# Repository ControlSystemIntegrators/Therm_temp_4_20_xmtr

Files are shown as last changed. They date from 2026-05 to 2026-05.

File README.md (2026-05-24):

# Analog 4–20 mA Thermistor Temperature Transmitter

A fully **analog** (no microcontroller) 2-wire 4–20 mA temperature transmitter
built from **standard, multi-sourced parts** — and a worked tutorial in the
instrumentation theory behind it.

It does two jobs:

1. **A teaching reference.** If you've ever wanted to understand how a 4–20 mA
   transmitter actually works — loop power, sensor excitation, linearization,
   zero/span calibration — this is a complete, honest, end-to-end example with
   the math shown and a calculator you can run.
2. **A real instrument.** It was designed for **chocolate temperature control**
   (the 20–40 °C tempering/working range), as a more accurate and more robust
   replacement for thermocouples. But it is parameterized: point the included
   calculator at *your* thermistor and *your* temperature band and it tells you
   which resistors to fit.

> **Why analog?** You can absolutely bolt a microcontroller and a 12-bit ADC on
> top of this for fine digital adjustment — see [Optional digital
> upgrade](#optional-digital-upgrade). In practice, for "hold a setpoint in a
> known band" process control, that layer is rarely worth the complexity. This
> project deliberately stays in the analog domain so the whole signal path is
> visible and every part is replaceable.

> **Not a safety device.** This is a process measurement instrument, not a
> safety-rated (SIL) one. Don't use it as a protective function.

---

## Specifications (default build)

| Parameter | Value |
|---|---|
| Output | 4–20 mA, 2-wire loop-powered |
| Loop supply | 7–30 V (24 V typical) |
| Default range | **20–40 °C → 4–20 mA** (chocolate) |
| Sensor | NTC thermistor, 10 kΩ @ 25 °C, β ≈ 3892 K (e.g. Omega 44006) |
| In-band accuracy | **±0.1 °C over the 20 °C band** (realistic system figure; the electronics + linearization contribute only ~±0.06 °C — sensor interchangeability, self-heating and lead effects dominate) |
| Calibration | zero + span trimpots, non-interactive |
| Quiescent current | ~2.6 mA (fits under the 4 mA floor) |
| Components | jellybean / multi-sourced; op-amps in SOT-23-5 |

Outside the chosen band the output saturates near 4 mA (cold) or 20 mA (hot) —
intentional. Accuracy is only specified inside the band.

---

## How a 4–20 mA transmitter works (the theory)

**The current loop.** A 2-wire transmitter sits in series with a DC supply and
a receiver. The transmitter's job is to *draw a controlled current* from the
loop — 4 mA represents the bottom of the range, 20 mA the top — regardless of
loop voltage or wiring resistance (within limits). Because the *current* is the
signal, voltage drops in long cable runs don't corrupt the reading, and a broken
wire reads 0 mA (a detectable fault, distinct from a valid 4 mA "low"). That
noise immunity and fault detection is why 4–20 mA has survived for decades in
industry.

**Loop-powered ("2-wire").** The same two wires that carry the signal also power
the transmitter. The catch: the *entire* circuit must run on **less than 4 mA**,
because that floor is the lowest the loop ever provides. Every microamp the
electronics draw is part of the loop current, so the design budgets quiescent
current carefully and lets an output ("dump") transistor make up the difference
to hit the commanded 4–20 mA.

**Why a thermistor?** An NTC thermistor is cheap, has a large signal (thousands
of ohms change over our band), is available with tight interchangeability
(±0.1–0.2 °C for the Omega 44000 series), and needs no cold-junction
compensation like a thermocouple. Its one drawback is that it is **very
nonlinear** — which is the interesting part of this design.

---

## The nonlinearity problem (and the one-resistor fix)

An NTC's resistance is approximately

```
R(T) = R25 · exp( β · (1/T − 1/298.15) )      [T in kelvin]
```

For our 10 kΩ part that's ~57 kΩ at −10 °C falling to ~3.6 kΩ at +50 °C — about
15:1, and badly curved. Fed straight into a linear amplifier you'd get large
errors away from one calibration point.

**The fix is a single resistor in parallel with the thermistor.** The parallel
combination `Rt ∥ Rlin` has an S-shaped curve with an inflection point; placing
that inflection at the *center* of your band makes the network resistance very
nearly linear in temperature there. The value for maximum linearity at center
temperature `Tc` (kelvin) is:

```
Rlin = Rt(Tc) · (β − 2·Tc) / (β + 2·Tc)
```

For the chocolate build (center 30 °C) the closed-form (unloaded) value is
~5.9 kΩ; the build uses **6.04 kΩ**, re-optimized for the gain-stage loading
(see [below](#dont-let-the-gain-stage-load-the-sensor)). Either way the residual
nonlinearity across 20–40 °C is only ~**±0.06 °C** — comfortably inside the
±0.1 °C system spec, so the linearization is never the limiting term.

### Why one resistor and not two

A second resistor *can* add a curvature-shaping term (by exciting through a
divider instead of a constant current), so we checked whether it's worth it.
For an NTC it essentially isn't — the optimizer drives the second resistor back
toward "constant current," and the conformity barely moves:

| Band → 4–20 mA | 1 resistor | 2 resistors |
|---|---|---|
| 20–40 °C | ±0.061 °C | ±0.057 °C |
| 15–45 °C | ±0.207 °C | ±0.188 °C |
| −10–50 °C | ±1.585 °C | ±1.545 °C |

~5% improvement for an extra precision part and an extra calibration
interaction. We dropped it. **The real lever is band width, not resistor count**
(see the table — the wider the band, the worse the conformity). Pick the
narrowest band that covers where your process actually operates.

### Don't let the gain stage load the sensor

There's a subtle trap the ideal math hides. The single-op-amp difference amp
(next stage) presents its input network — `R9 + R12` from the sensor node to
ground — as a *load* on node X. The sensor's source impedance there is the
linearized network (a few kΩ), so a low input impedance bleeds a
temperature-dependent current out of the node and **bows V(X)**, adding
nonlinearity the zero/span trims cannot remove.

We only caught this with the **device-level SPICE model** (the ideal netlist and
the first cut of `design.py` both assumed an infinite-impedance gain input). With
the original 10 k / 24.9 k divider (`R9+R12 ≈ 35 kΩ`) loading a ~4 kΩ source, the
in-band conformity blew out to **±0.18 °C** — past the spec. Two fixes, both
verified:

1. **Raise the gain-stage input impedance** so it stops loading the node — this
   build uses `R9=R10=100 kΩ`, `R11=R12=249 kΩ` (`R9+R12 ≈ 349 kΩ`, ~1 % loading).
2. **Re-optimize R1** for whatever loading remains — `design.py` now models the
   load (`--rload`) and searches for the best linearization resistor rather than
   trusting the unloaded closed form (hence 6.04 kΩ, not 5.9 kΩ).

With both, conformity is back to **±0.058 °C**, confirmed in the device-level
sim. Lesson: a difference amp driven from a non-trivial source impedance must
have an input impedance well above it, or you pay for it in linearity.

You can reproduce all of this — and design for your own sensor/range — with
[`tools/design.py`](tools/design.py).

---

## Circuit overview

Two views: the **signal chain** (what computes the current) and the
**power/output loop** (how a 2-wire device powers itself and sets loop current).

### Signal chain

```
 Vref(2.5V) ──[ NTC ∥ Rlin ]──● X ─────────────►┌────────────┐
                              │                 │   A2       │
              A1 sinks Iexc ──┘                 │ gain/zero  │─ Vcmd ─►┌──────────┐
              (0.25 mA, constant)               │  (2 pots)  │         │ A3 servo │─► loop
                                                └────────────┘         │  + Q2    │   current
   V(X) = Vref − Iexc·(NTC ∥ Rlin)                                     └──────────┘
        (rises with temperature)        Vcmd = SPAN·(V(X) − ZERO)   Iloop = Vcmd / Rsense
```

A constant current is pulled through the linearized network, so the node voltage
`V(X)` is a clean, near-linear function of temperature. The gain/zero amplifier
scales and offsets it; the output stage turns that command voltage into loop
current.

### Power / output loop

```
 LOOP+ ──▷|──┬───────────────────────────────┬──────────► IN (raw 7..30 V)
   (24 V) D1 │                               │
           TVS         pre-reg: Q1 + TL431 ───┤────────► VL (+5 V) ─► Vref, A1, A2, A3
            │          (series NPN follower)  │
            │                                 └────────► Q2 collector (dump)
            │                                                  │ emitter
 LOOP- ─────┴────────────────[ Rsense 50Ω ]──────  AGND ───────┘
                                    ▲
                A3 drives Q2 so that  Iloop · Rsense = Vcmd
```

Everything returns to `AGND` and flows out through `Rsense`, so the
sense resistor sees the **total** loop current — the electronics' own ~2.6 mA
quiescent draw plus whatever the dump transistor `Q2` adds. A3 servos `Q2` until
that total equals `Vcmd / Rsense`. Because quiescent draw (~2.6 mA) is below the
4 mA floor, `Q2` always has something to add.

### Stage-by-stage

| Stage | Parts | Function | Key relation |
|---|---|---|---|
| Protection | D1 (Schottky), TVS | reverse-polarity + surge | — |
| Pre-regulator | Q1 (NPN follower), TL431, divider, + Q4/Q5 bias source | makes the +5 V rail `VL` from the loop; **series** pass, not shunt, so it draws only what the electronics need. Q4/Q5 form a 2-transistor constant-current source (a jellybean replacement for a current-regulating diode) that biases the TL431 flat across the 7–30 V loop | `VL = 2.5·(1+Rfa/Rfb)` |
| Reference | LM4040-2.5 | 2.500 V for excitation + zero | — |
| Excitation | A1, Q3, Rexc | constant `Iexc = Vref/Rexc = 0.25 mA` pulled through `NTC∥Rlin` | `V(X)=Vref − Iexc·Rnet` |
| Linearization | Rlin (6.04 kΩ) | straighten the curve in-band | `Rlin = Rt(Tc)·(β−2Tc)/(β+2Tc)`, re-optimized for load |
| Gain/Zero | A2 + **span pot** + **zero pot** | scale & offset to the command voltage | `Vcmd = SPAN·(V(X) − ZERO)` |
| Output | A3, Q2, Rsense | servo loop current to the command | `Iloop = Vcmd / Rsense` |

> **The three knobs are orthogonal**, which makes calibration sane:
> **Rlin** depends only on the band *center*, **span** on the band *width*, and
> **zero** on the band *position*. Move the band up/down → re-zero only. Widen
> it → re-span only. Re-center it → change Rlin.

---

## Selecting components for your own range

Run the calculator with your sensor and the two temperatures you want at 4 mA
and 20 mA:

```
python3 tools/design.py --r25 10000 --beta 3892 --tlow 20 --thigh 40
```

It prints the linearization resistor, the excitation resistor, the span (gain)
and zero (offset) targets, the conformity error you'll get, the self-heating
estimate, and a transfer table. Defaults are the chocolate build. Output for the
default:

```
--- Linearization ---
Rlin (E96)      : 6.040 kohm   <- re-optimized for gain-stage loading
Conformity      : +/- 0.059 C
--- Excitation ---
Rexc (E96)      : 10.000 kohm  -> Iexc = 0.2500 mA
--- Amplifier / output stage ---
SPAN  (gain)    : 2.5706 V/V   <- set by span pot
ZERO  (Vzero)   : 1.3872 V     <- set by zero pot
```

**Manual recipe** (what the script does):

1. **Center → Rlin.** `Tc = (Tlow+Thigh)/2`; `Rlin = Rt(Tc)·(β−2Tc)/(β+2Tc)`,
   rounded to the nearest E96 value.
2. **Excitation.** Pick `Iexc` (~0.25 mA is a good balance of signal size vs.
   self-heating); set `Rexc = Vref / Iexc`.
3. **Edge voltages.** `V(X) = Vref − Iexc·(Rt ∥ Rlin)` at `Tlow` and `Thigh`.
4. **Span (gain).** `SPAN = (20mA−4mA)·Rsense / (V(X)@Thigh − V(X)@Tlow)`.
5. **Zero (offset).** Choose `ZERO` so the output is 4 mA at `Tlow`.

Then check the printed conformity. If it exceeds your target, your band is too
wide — narrow it (see the table above).

---

## Calibration

You need a way to present two known temperatures (a stirred ice/water-and-warm
bath, a dry-block calibrator, or — easiest for bench bring-up — **two precision
resistors** substituted for the probe equal to `Rt(Tlow)` and `Rt(Thigh)`, which
the calculator prints).

1. Apply the **low** point (`Tlow`, e.g. 20 °C → `Rt = 12.49 kΩ`). Adjust the
   **ZERO** pot for **4.00 mA**.
2. Apply the **high** point (`Thigh`, e.g. 40 °C → `Rt = 5.35 kΩ`). Adjust the
   **SPAN** pot for **20.00 mA**.
3. Repeat once. Zero and span interact only slightly (the gain term scales the
   zero point a little), so a second pass nails both to within a microamp.

Use a loop calibrator or a 250 Ω precision resistor + DMM (1.000–5.000 V = 4–20
mA) to read the current.

---

## Bill of materials (multi-sourced)

Every active part below is available from multiple manufacturers, or in a
footprint with many drop-in alternatives. That is a design goal: this instrument
should be repairable for decades without a single-source IC.

| Ref | Part | Function | Second-source notes |
|---|---|---|---|
| RT1 | NTC 10 kΩ, β≈3892 (Omega 44006 / equiv.) | sensor | any 10k NTC with known β; re-run calculator for other betas |
| Rlin | 6.04 kΩ, 1%, ≤25 ppm/°C | linearization | passive, universal |
| U1 | LM4040-2.5 (2.500 V) | reference | TI, ADI, Diodes, ON |
| U2 | TL431 (2.5 V shunt ref) | pre-reg reference | TI, ON, Diodes, ST, UTC — *the* multi-sourced jellybean; KiCad sym `TL431DBZ` (SOT-23) |
| Q1 | NPN small-signal (MMBT3904 / BC847) | pre-reg pass (follower) | universal |
| Q2 | NPN, ~0.5 W (SOT-223, e.g. BCP56 / PZTA42) | output dump transistor | universal; **see thermal note** |
| Q3 | NPN small-signal (MMBT3904 / BC847) | excitation current sink | universal |
| A1–A3 | µpower precision op-amp, **SOT-23-5** (OPA333 / MCP6V31 / TLV9061-class) | excitation, gain/zero, output servo | by exact PN limited; by SOT-23-5 footprint, dozens of swappable parts |
| Rexc | 10.0 kΩ, 1%, ≤25 ppm/°C | sets Iexc | passive |
| Rsense | 49.9 Ω (or 50 Ω), 1%, ≤25 ppm/°C | loop sense | passive |
| Rfa/Rfb | 10.0 kΩ / 10.0 kΩ, 1% | sets VL = 2.5·(1+Rfa/Rfb) = 5 V | passive |
| RV1 | zero trim, SMD multiturn cermet (e.g. 3269 / 3224) | ZERO | universal |
| RV2 | span trim, SMD multiturn cermet | SPAN | universal |
| D1 | Schottky SMA (SS14 / BAT54) | reverse polarity | universal |
| TVS1 | SMAJ33A (or per supply) | surge | universal |
| C1–Cn | 100 nF + 1–10 µF bypass | decoupling | universal |

**Thermal note (Q2).** A 2-wire transmitter must drop the loop voltage somewhere;
that's Q2. Worst case ≈ (instrument voltage) × (loop current) ≈ 20 V × 20 mA ≈
**0.4 W**. Use a SOT-223 (or larger) device with adequate copper, or split the
drop with a series resistor ahead of Q2's collector.

**Op-amp footprint.** Standardizing A1–A3 on **SOT-23-5 singles** is deliberate:
precision op-amps are mostly single-source by part number, but the SOT-23-5
single-op-amp pinout is a de-facto industry standard with many footprint-
compatible options, so a substitute is always a re-qualification away, never a
redesign.

---

## Simulation

[`sim/transmitter.cir`](sim/transmitter.cir) models the ideal signal chain
(reference + op-amps as behavioral sources, NTC as a temperature-dependent
resistor) and DC-sweeps temperature to confirm the 4–20 mA transfer and in-band
linearity.

```
ngspice -b sim/transmitter.cir   # DC-sweeps temperature; prints Iloop vs T
```

(LTspice: change the behavioral-resistor `r='...'` syntax to `R=...`.)

It has been run with **ngspice 46**; the full output is saved in
[`sim/SIM_RESULTS.txt`](sim/SIM_RESULTS.txt). Key points (Iloop = Vcmd / 50 Ω):

| T (°C) | V(x) | Vcmd | Iloop |
|---|---|---|---|
| 20 | 1.49812 V | 0.20009 V | **4.00 mA** |
| 30 | 1.64825 V | 0.59996 V | **12.00 mA** |
| 40 | 1.79854 V | 1.00024 V | **20.00 mA** |
| <20 | — | clamps 0.190 V | 3.8 mA (under-range) |
| >40 | — | clamps 1.025 V | 20.5 mA (over-range) |

The node voltages match `tools/design.py` to the millivolt, and the in-/out-of-
band clamping behaves as designed.

**Verification status (be honest about it):**

- ✅ Signal-chain transfer and linearization conformity (~**±0.06 °C**, well
  inside the **±0.1 °C** system spec) — verified in `tools/design.py` **and
  confirmed in ngspice** (table above).
- ⬜ Discrete output stage (the Q1 pre-regulator and the Q2/A3 servo loop,
  including loop stability and Q2 thermals) — **designed but not yet
  device-level simulated or bench-verified.** The netlist above models the
  op-amps as ideal behavioral sources, so it validates the *transfer math*, not
  the real parts. Simulate with device models and prototype before trusting it.

---

## Optional digital upgrade

If you later want digital trim, datalogging, or a nonlinear curve over a wide
range, you can add an MCU with a ≥12-bit ADC reading `V(X)` and driving the loop
via a current-output DAC (or by replacing the A3/Q2 stage). For a "hold a
setpoint in a known band" application this is usually unnecessary complexity —
the analog path here already beats thermocouple accuracy in-band — but the
sensor front-end and linearization theory carry over unchanged.

---

## Working with KiCad — notes and gotchas

Taking this from netlist to schematic to PCB surfaced a few KiCad limitations
worth recording — both for anyone reproducing the board and for anyone doing a
careful (or AI-assisted) review of a `.kicad_sch`:

- **Connectivity can't be read reliably from the `.kicad_sch` text.** Symbol
  mirror/rotation transforms and overlapping wire segments defeat any attempt to
  infer "what's connected to what" from pin coordinates. Let KiCad compute it
  instead — `kicad-cli sch export netlist --format kicadsexpr -o net.net
  therm.kicad_sch` — and read the nets. Every net-by-net review of this board was
  done that way, not by eyeballing the schematic file.

- **ERC does not catch wrong *values* or wrong *roles*.** Several real errors
  here passed connectivity checks clean: a `49.9 kΩ` loop-sense resistor that
  should have been `49.9 Ω`; a bypass cap with *both* pins on the same net (a
  no-op); an op-amp powered from the 2.5 V reference instead of the 5 V rail; and
  the LM4040 reference wired across the loop input as if it were the TVS. None of
  these trip ERC — they need an explicit value-and-node audit against intent.

- **Symbol variants have different pin numbering.** The OPA333 in SOIC-8
  (`OPA333xxD`) uses pins 2/3/4/6/7; in SOT-23-5 (`OPA333xxDBV`) it's 1–5. Grab
  the wrong variant and the schematic *looks* right while the netlist is wrong —
  always confirm the symbol's package/pinout matches the footprint you intend.

- **Not every jellybean part is in the stock library.** The TL431 is
  (`Reference_Voltage:TL431DBZ`); the TLV431 is not, which had forced a custom
  symbol — one reason we standardized on the TL431. Preferring stock-library
  parts avoids custom-symbol upkeep.

- **Footprints aren't auto-assigned.** Symbols sit with an empty footprint until
  you assign one, and nothing warns you until you try to lay out the board — the
  two trimpots were caught this way. Sweep for missing footprints before routing.

- **File hygiene.** KiCad scatters `*-backups/` zips, `~*.lck` locks,
  `#auto_saved_files#`, and per-user `*.kicad_prl` state through the project; the
  [`.gitignore`](.gitignore) excludes them so only the real design files track.

**Takeaway:** a parameterized calculator proves the design *intent*, and ERC
proves the nets are *connected* — but neither flags a wrong value, a wrong
package variant, or a node that's electrically valid yet functionally pointless.
A net-by-net netlist review plus a device-level SPICE pass are what actually
prove the *instrument*.

---

## Repository layout

```
Therm_temp_4_20_xmtr/
├── README.md                    # this file
├── LICENSE                      # MIT
├── docs/
│   └── DESIGN_CONVERSATION.md   # the prompts that drove the design + decisions
├── hardware/
│   └── BOM.md                   # bill of materials (consolidated values, tempco notes)
├── tools/
│   └── design.py                # parameterized design calculator (models gain-stage load)
├── sim/
│   ├── transmitter.cir          # ideal transfer-function verification
│   ├── device_level.cir         # discrete model (real BJTs + IC macromodels)
│   └── SIM_RESULTS.txt          # captured ngspice 46 output
└── therm_kicad/                 # KiCad project: schematic + rough PCB
    └── therm/                   # therm.kicad_sch / .kicad_pcb / .kicad_pro
```

For *how* this design came to be — the design conversation and the reasoning
behind each choice — see [`docs/DESIGN_CONVERSATION.md`](docs/DESIGN_CONVERSATION.md).

Status: schematic + a rough PCB are in `therm_kicad/`; the device-level SPICE
model verifies the discrete signal chain. Still open: output-stage **loop
stability** (AC/transient) and **bench bring-up**.

## License

[MIT](LICENSE). Use it, build it, sell it — just keep the copyright notice.

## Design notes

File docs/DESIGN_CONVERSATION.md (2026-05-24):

# How this was designed — the driving prompts

This project was designed interactively, in conversation with an AI assistant
(Claude / Claude Code). It's published here partly *because* the back-and-forth
is itself a decent walkthrough of how you reason about an analog instrument:
each prompt below narrowed the design space, and the decision it produced is
noted underneath.

Prompts are the human's, reproduced in order. (The structured multiple-choice
answers were posed by the assistant; the human's selection is shown.)

---

**1.** *"hey are you any good at analog circuits?"*

> Opening. Established scope.

**2.** *"I am interested in making an analog 4-20ma temperature transmitter for
tempature measurement in the range of -10-50degC. Accuracy is only really
critical in a small range of temperatures, 20-40degc. I would like to use a
thermistor as the measurement source. I am thinking probes such as these
[Omega ON-960-44000 non-linear thermistor probe]."*

> The core spec: −10…50 °C range, tight accuracy only in 20–40 °C, NTC
> thermistor (10 kΩ @ 25 °C, β ≈ 3892). The "accuracy only matters in a band"
> constraint became the central lever of the whole design.

**3.** Assistant asked: power architecture? accuracy? build style?
Human: **3-wire/4-wire**, **±0.1–0.2 °C**, and asked
*"what's the cost difference in parts between the purpose built ic architecture
and the fully discrete solution?"*

> Answer: roughly a wash (~$16 vs ~$18 in single quantities) — the integrated
> loop IC (XTR116) bundles the reference + output stage that you'd otherwise buy
> discretely.

**4.** *"are there pin compatible semiconductors from other manufacturers for
the xtr106?"*

> Answer: no — the entire XTR1xx family (and every integrated 4–20 mA loop
> transmitter IC) is single-source.

**5.** *"ok, let's consider it a 2-wire instrument. The reason that I want pin
compatibility from multiple manufacturers is because I want to make sure that
the product is always maintainable."*

> The decisive constraint. Because no integrated loop IC is multi-sourced,
> maintainability forces a **fully discrete design from jellybean parts**. This
> set the whole BOM philosophy.

**6.** Assistant proposed band-anchoring + a parallel linearization resistor.
Human: *"those resistors for linearization — one adjusts the zero? and one the
span? and they are non-interactive? I think band anchored is probably OK. I
would want instructions for selecting the components to anchor the band around
particular values…"*

> Clarified the orthogonal-knobs model: linearization (curve), zero (position),
> span (width) are separate. Drove the requirement for a **parameterized
> component-selection recipe** (now `tools/design.py` + the README).

**7.** *"I think that standardizing around SOT23-5 is the way to go."*

> Op-amps fixed to the SOT-23-5 footprint — a de-facto multi-vendor standard,
> serving the maintainability goal.

**8.** *"I am ok with a dual linearization resistor approach, in that case, and
I would hope for a zero and span potentiometer for calibration."*

> Triggered a numerical comparison of one- vs two-resistor linearization. The
> result: the second resistor buys only ~5% for an NTC, so it was **dropped**.
> Zero + span trimpots stayed.

**9.** Assistant asked which band → 4–20 mA. Human: *"20–40 deg C is fine. I
would prefer a readme that describes how to select components to meet particular
ranges… my application, which is chocolate temperature control. Right now, we
are using thermocouples, which are not very accurate, and the temperatures that
we care about are 20–40C. … a microprocessor can be added to this using a 12-bit
adc … but practically speaking, that adds a very complicated layer … which …
is pretty much never needed."*

> Locked the default range (20–40 °C), the real application (chocolate, replacing
> thermocouples), the dual mission (working instrument **and** teaching repo),
> and the "stay analog" stance.

**10.** *"we can do an ngspice analysis. also a git init. Roll this out as
'Therm_temp_4_20_xmtr' repo."*

> Verification + packaging. (ngspice 46 was installed portable; the netlist
> confirms 4.00/12.00/20.00 mA at 20/30/40 °C — see `sim/SIM_RESULTS.txt`.)

**11.** *"please proceed, but with email as bruce@controlsysint.com"* —
git identity.

**12.** *"we can use the controlsysint remote…"* — published to the
ControlSystemIntegrators GitHub account.

**13.** *"also, MIT license is fine for this."* — see `LICENSE`.

**14.** *"feel free as well to include a transcript of the prompts that drove
this effort."* — this file.

---

### The throughline

A single constraint — *"accuracy only matters in 20–40 °C"* — combined with
*"it must always be maintainable"* drove every major choice: band-anchored
calibration, a single parallel linearization resistor, a discrete signal chain
of multi-sourced parts, SOT-23-5 op-amps, and a parameterized calculator so the
same design retargets to any sensor and band.

---

## Round 2 — design review, jellybean/SMD pass, and device-level verification

A second pass took the design from "math validated" to "schematic + PCB," and
in doing so caught several real issues. The driving prompts, in order:

**15.** *"a part more common than TLV431… is there a more common adjustable
shunt regulator?"*

> Swapped the pre-regulator reference **TLV431 → plain TL431** (the most
> second-sourced shunt regulator in existence, and in KiCad's stock library as
> `TL431DBZ`, 3-lead SOT-23 — the TLV431 was a custom symbol). Divider became
> R3=R4=10 k for `VL = 2.5·(1+R3/R4) = 5 V`. Cost: ~+1 mA bias (TL431 needs
> ~1 mA min cathode current) — accepted for ubiquity + a stock symbol.

**16.** *"glad to make a completely jellybean design."*

> The current-regulating diode biasing the reference was the only specialty
> semiconductor left. Replaced it with a **2-transistor constant-current source**
> (Q4/Q5 = MMBT3906 ×2 + R17/R18) — all jellybean, ~1.5 mA, flat over the
> 7–30 V loop.

**17.** *"I would like everything to be surface mount."*

> Trimpots → SMD multiturn (Bourns 3269/3224), D1 → SS14 (SMA). The **only**
> through-hole parts left are the field-wiring terminal blocks — a deliberate
> exception for pull-out strength.

**18.** *"reframe it to ±0.1 °C over 20 °C"* (after a tolerance/tempco review).

> Established that two-point calibration absorbs gain/offset error, so **initial
> tolerance can be 1 % everywhere**; only **tempco** matters, and only on the
> single-ended R1/R8/R16 (keep ≤25 ppm/°C). The headline spec was reframed from
> a false-precision ±0.06 °C to an honest **±0.1 °C over the band**, since sensor
> interchangeability and self-heating dominate anyway.

**19.** *"minimize the total number of different kinds of resistors."*

> Consolidated to **8 distinct resistor values** by re-spec'ing where the value
> is calibrated out (e.g. R2→2.49 k, R12→24.9 k, R13→10 k, R18→100 k).

**20.** *"a wire-by-wire of the … circuit"* → full netlist review.

> Walked the schematic net-by-net (via `kicad-cli` netlist export, not coordinate
> parsing). Caught and fixed: A1 powered from VREF instead of VL; the LM4040
> reference miswired across the loop input as if it were the TVS; D1 reversed; a
> fragmented IN rail with Q2's collector islanded; missing R2; and a 49.9 kΩ
> loop-sense typo (should be 49.9 Ω).

**21.** *"write the device-level netlist"* → discovered a spec-breaking flaw.

> A device-level SPICE model (real BJTs + behavioral OPA333/LM4040/TL431) showed
> the single-op-amp difference amp's input network (`R9+R12`) **loads the sensor
> node**, bowing V(x) to **±0.18 °C** — past spec. The ideal netlist and the
> first `design.py` both missed it (they assumed infinite input impedance). Fix:
> raise the diff-amp input impedance (`R9=R10=100 k`, `R11=R12=249 k`) **and**
> re-optimize R1 (→6.04 k). `design.py` now models the load (`--rload`); the
> device sim confirmed conformity back to **±0.058 °C**.

**22.** *"verify resistor and capacitor values"* + cap connectivity review.

> Reconciled every cap to its actual node (C1 = A1 decoupling, C7 = VREF bypass,
> etc.) and added input-rail decoupling (C8 bulk + C9 bypass, IN↔AGND).

**23.** *"I did a rough PCB layout. Push that and the schematic up."*

> Schematic + PCB committed alongside the updated BOM, README, calculator, and
> the device-level netlist.

### The Round-2 throughline

The math was right from Round 1, but **the physical circuit had bugs the ideal
model couldn't show** — a loaded sensor node, mis-wired references, a sense-
resistor typo. The lesson: a parameterized calculator proves the *intent*; a
net-by-net review and a *device-level* sim are what prove the *instrument*.

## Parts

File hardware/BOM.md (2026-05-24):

# Bill of Materials

Design-candidate BOM for the analog 2-wire 4–20 mA NTC transmitter
(default build: 20–40 °C → 4–20 mA, chocolate temperature control).

> **Status:** the *functional* parts list is complete and orderable. A handful
> of bias/compensation values (marked **nominal**) may shift slightly once we
> finalize the interconnections and run the device-level simulation — they don't
> affect what you buy, only trim values. Machine-readable copy: [`BOM.csv`](BOM.csv).

Every active part is multi-sourced or in a footprint with many drop-in
alternatives — maintainability is the design goal.

---

## Reference designators by stage

### Sensor & linearization
| Ref | Value | Tol/Grade | Description |
|---|---|---|---|
| RT1 | NTC 10 kΩ @ 25 °C, β≈3892 | ±0.1–0.2 °C interch. | Thermistor probe (Omega 44006 / ON-960-44xxx), wired to TB1 |
| R1 | 6.04 kΩ | 1%, ≤25 ppm/°C | **Linearization** resistor, parallel with RT1 (tempco-critical; re-optimized for gain-stage loading) |

### Voltage reference
| Ref | Value | Tol/Grade | Description |
|---|---|---|---|
| U1 | LM4040-2.5 (2.500 V) | A/B grade | Shunt voltage reference |
| R2 | 2.49 kΩ | 1% | U1 bias from VL (≈1.0 mA, keeps LM4040 above its load) |
| C7 | 100 nF | X7R | VREF_U1 reference bypass |

### Pre-regulator (makes the +5 V rail VL from the loop)
| Ref | Value | Tol/Grade | Description |
|---|---|---|---|
| Q1 | MMBT3904 (NPN) | — | Series-pass emitter follower |
| U2 | TL431 (any second-source; KiCad sym `TL431DBZ`, SOT-23) | — | Adjustable shunt reference, 2.5 V (sets VL) |
| Q4 | MMBT3906 (PNP) | — | Bias current source — high-side pass device (feeds U2 cathode + Q1 base) |
| Q5 | MMBT3906 (PNP) | — | Bias current source — current-sense device (limits Q4) |
| R17 | 432 Ω | 1% | Sets bias current `I ≈ 0.65 V / R17 ≈ 1.5 mA` (Q4 emitter) |
| R18 | 100 kΩ | 1% | Q4 base pull-down (turn-on), returned to AGND |
| R3 | 10.0 kΩ | 1% | VL feedback divider, top |
| R4 | 10.0 kΩ | 1% | VL feedback divider, bottom → VL ≈ 2.5·(1+R3/R4) = 5.00 V |
| R5 | 100 kΩ | 1% | Q1 base–emitter (clean turn-off) — *nominal* |
| C2 | 1 µF | X7R 50 V | VL bulk decoupling |

### Excitation (constant-current sink, 0.25 mA through RT1‖R1)
| Ref | Value | Tol/Grade | Description |
|---|---|---|---|
| A1 | OPA333 (SOT-23-5) | — | Current-sink servo amp |
| Q3 | MMBT3904 (NPN) | — | Current-sink pass device |
| R6 | 10.0 kΩ | 1% (matched) | Setpoint divider top (Vref → Vsp ≈ 0.5 V) |
| R7 | 2.49 kΩ | 1% (matched) | Setpoint divider bottom |
| R8 | 2.00 kΩ | 1%, ≤25 ppm/°C | Sink emitter resistor → **sets Iexc = Vsp/R8 ≈ 0.25 mA** (tempco-critical) |
| C3 | 100 pF | C0G | A1 loop compensation — *nominal* |

### Gain / Zero amplifier (difference amp + calibration pots)
| Ref | Value | Tol/Grade | Description |
|---|---|---|---|
| A2 | OPA333 (SOT-23-5) | — | Gain/zero (span) amplifier |
| R9 | 100 kΩ | 1% (matched) | Diff-amp input (V(X)) — high-Z to avoid loading node X |
| R10 | 100 kΩ | 1% (matched) | Diff-amp input (Vzero) |
| R11 | 249 kΩ | 1% (matched) | Diff-amp feedback (fixed part of SPAN) |
| R12 | 249 kΩ | 1% (matched) | Diff-amp CMRR-match resistor (= R11; small gain mismatch is calibrated out) |
| RV1 | 50 kΩ cermet, multiturn, **SMD** (Bourns 3269 / 3224) | — | **SPAN** trim (in series with R11 → gain 2.49–2.99) |
| R13 | 100 kΩ | 1% | Zero network, top (Vref side) → Vzero range 1.0–1.5 V (sized for the 50 kΩ pot) |
| R14 | 100 kΩ | 1% | Zero network, bottom (AGND side) |
| RV2 | 50 kΩ cermet, multiturn, **SMD** (Bourns 3269 / 3224) | — | **ZERO** trim (wiper = Vzero ≈ 1.0–1.5 V) |
| C4 | 1 nF | C0G | Feedback noise filter (~6 kHz) — *nominal* |
| C5 | 100 nF | X7R | Zero-node bypass |

### Output stage (2-wire current servo)
| Ref | Value | Tol/Grade | Description |
|---|---|---|---|
| A3 | OPA333 (SOT-23-5) | — | Loop-current servo amp |
| Q2 | BCP56-16 (NPN, SOT-223) | ≥1 W, ≥80 V | **Dump transistor** — drops the loop voltage; see thermal note |
| R16 | 49.9 Ω | 1%, ≤25 ppm/°C | Loop current sense (Iloop = Vcmd / R16) (tempco-critical) |
| R15 | 2.49 kΩ | 1% | Q2 base drive — *nominal* |
| C6 | 10 nF | X7R | Output servo-loop compensation — *nominal* |

### Protection & I/O
| Ref | Value | Tol/Grade | Description |
|---|---|---|---|
| D1 | SS14 (SMA) | Schottky, ≥40 V | Reverse-polarity protection (series in LOOP+) |
| TVS1 | SMAJ33A | uni-dir | Surge clamp across loop |
| C8 | 1 µF | X7R 50 V | Input bulk (IN ↔ AGND) |
| C9 | 100 nF | X7R 50 V | Input bypass (IN ↔ AGND) |
| C1, C10, C11 | 100 nF ×3 | X7R | Op-amp decoupling — one per A1/A2/A3 (at pin 5 ↔ AGND) |
| TB1 | 2-pos terminal block, 5.08 mm | — | Thermistor probe leads |
| TB2 | 2-pos terminal block, 5.08 mm | — | 4–20 mA loop (LOOP+ / LOOP−) |

---

## Op-amp choice (A1–A3)

**OPA333** (SOT-23-5) is the reference part: 17 µA supply current each (51 µA
total — easily inside the loop budget), 10 µV offset, 0.05 µV/°C drift, 5.5 V max
supply. Standardizing on the **SOT-23-5 single-op-amp footprint** means many
pin-compatible alternatives (ADA4505-1, MCP6V11, TLV9061, LPV811-class) can drop
in — single-source by exact PN, multi-source by footprint.

## Thermal note (Q2)

A 2-wire transmitter must drop the loop voltage somewhere — that's Q2. Worst case
≈ (instrument voltage) × (loop current) ≈ 25 V × 20 mA ≈ **0.5 W**. The SOT-223
BCP56 handles it with adequate copper pour; if your loop supply is high, add a
small series resistor ahead of Q2's collector to share the dissipation.

## Current budget (why it fits 2-wire)

| Consumer | Current |
|---|---|
| 3 × OPA333 | ~0.05 mA |
| VREF_U1 path via R2 (LM4040 bias + 0.25 mA excitation + zero/setpoint dividers) | ~1.0 mA |
| Pre-reg bias (Q4/Q5 source) | ~1.5 mA |
| **Total quiescent** | **~2.6 mA** |

Under the 4 mA floor with ~1.4 mA of margin; the dump transistor Q2 supplies the
difference up to 20 mA.

> **Why the bias source is 1.5 mA, and why it's two transistors.** U2 is a
> standard **TL431**, which needs ~1 mA minimum cathode current to regulate. The
> bias source feeds U2's cathode plus Q1's base (~8 µA), so it's sized to ~1.5 mA
> to keep U2 in regulation with margin. It must be a *constant* current (not a
> resistor) because the voltage across it swings ~1.3–24 V over the 7–30 V loop —
> a resistor would vary the current ~18:1 and blow the budget at high loop
> voltage. We build that constant current from **Q4/Q5 (MMBT3906 ×2) + R17/R18**
> rather than a current-regulating diode: a CRD is a specialty part with only a
> handful of second-sources, whereas this discrete source is all jellybean. Q5
> senses Q4's emitter current across R17 and throttles Q4 when `I·R17 ≈ 0.65 V`,
> giving `I ≈ 0.65 V / R17`. R18's own current returns to AGND (not the bias
> node) and stays a negligible ~15–80 µA across the loop range.
>
> The earlier TLV431 (1.24 V, ~0.1 mA min) allowed a 0.5 mA bias, but it isn't in
> KiCad's stock library and is less widely second-sourced. We took the +1 mA
> quiescent to land on the most-multi-sourced reference in existence with a stock
> symbol + footprint. If the budget is ever tight, the **ATL431** (2.5 V, ~35 µA
> min, same divider) buys it back — at the cost of fewer sources and a custom
> symbol.

---

## Tolerance & tempco

The two trimpots calibrate the instrument at two points (4 mA at Tlow, 20 mA at
Thigh), so **any pure gain or offset error is trimmed out**. That splits the
resistor spec into two very different requirements — *initial tolerance* (mostly
calibrated away) and *tempco* (drift after calibration, **not** calibrated away).

**Initial tolerance — 1% is fine almost everywhere.**
A gain/offset error just moves a trimpot. The only resistor whose tolerance
escapes calibration is **R1 (linearization)**, because it sets the *shape* of the
curve between the two anchored endpoints — and even there it's nearly free: a
1% R1 error widens conformity from ±0.060 °C to ±0.067 °C (±5% → ±0.10 °C). So
spec **1% tolerance on all of R1, R6–R12, R16**; the precision used to be 0.1%
but it bought essentially nothing here.

**Tempco — this is what actually matters, and only on three resistors.**
Drift happens after calibration, so it isn't trimmed. It bites hardest on the
**single-ended (non-ratio) resistors**, where there's no matching partner to
cancel against:

- **R16** (loop sense, `Iloop = Vcmd/R16`) — drifts output gain 1:1.
- **R8** (excitation set, fixes Iexc) — drifts the signal slope.
- **R1** (linearization) — drift slightly reshapes the network.

At 100 ppm/°C (typical 1% thick-film) these add roughly **0.04–0.05 °C each over a
20 °C ambient swing**; at ≤25 ppm/°C they're ~4× smaller. So keep **R1, R8, R16
at ≤25 ppm/°C** (1%-tolerance / 25-ppm thin-films are cheap) — that keeps the
ambient drift comfortably inside the ±0.1 °C system spec. At 100 ppm/°C the
stacked drift of these three can eat much of that budget over a wide ambient
range, on top of the sensor's own ±0.1–0.2 °C interchangeability.

**Ratio groups — 1%/100 ppm OK if bought matched.**
R6/R7 (excitation divider) and R9/R10/R11/R12 (diff-amp) work as *ratios*, so if
they're the same series/material their tempcos track and largely cancel. 1% is
fine; a matched resistor network for the diff-amp set is ideal but not required.

| Class | Refs | Spec |
|---|---|---|
| Single-ended, drift-critical | **R1, R8, R16** | 1%, **≤25 ppm/°C** |
| Ratio / matched | R6, R7, R9, R10, R11, R12 | 1% (same series) |
| Bias / divider / non-critical | R2, R3, R4, R5, R13, R14, R15, R17, R18 | 1% |
| Caps | C3, C4 timing/filter | **C0G**; all bypass/bulk **X7R** |

## Packaging

The board is **all surface-mount** — every active part is SOT-23 / SOT-23-5 /
SOT-223, and all R/C, the trimpots (SMD multiturn), D1 (SS14, SMA) and TVS1
(SMA) are SMD. The **only through-hole parts are TB1/TB2**, the field-wiring
terminal blocks — a deliberate exception, because TH gives the pull-out strength
an SMD terminal block can't for a probe/loop cable that gets tugged in service.

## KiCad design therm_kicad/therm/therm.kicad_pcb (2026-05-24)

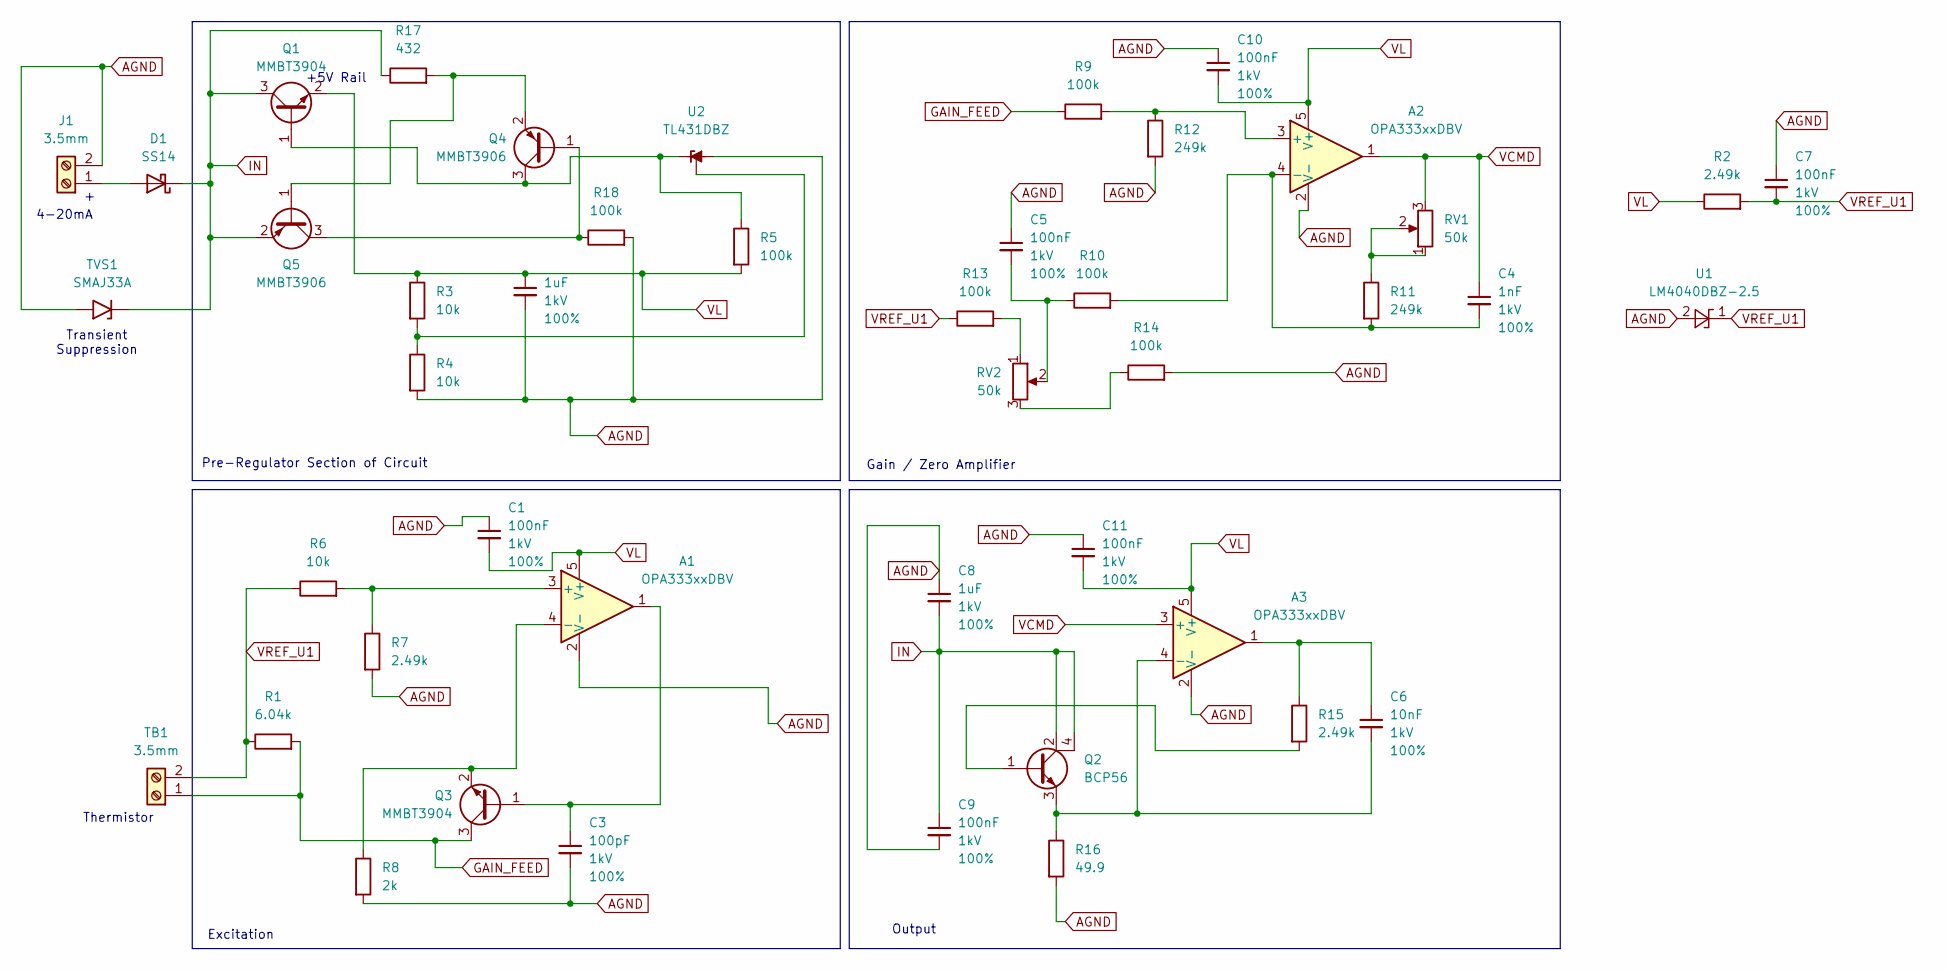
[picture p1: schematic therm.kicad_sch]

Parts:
A1, A2, A3: OPA333xxDBV; SOT-23-5
C1, C5, C7, C9, C10, C11: 100nF; C_0603_1608Metric; Voltage 1kV; Tolerance 100%
C2, C8: 1uF; C_0603_1608Metric; Voltage 1kV; Tolerance 100%
C3: 100pF; C_0603_1608Metric; Voltage 1kV; Tolerance 100%
C4: 1nF; C_0603_1608Metric; Voltage 1kV; Tolerance 100%
C6: 10nF; C_0603_1608Metric; Voltage 1kV; Tolerance 100%
D1: SS14; D_SMA
J1: 3.5mm; ScrewTerminal_1x02_P3.5mm_Horizontal_Black
Q1, Q3: MMBT3904; SOT-23
Q2: BCP56; SOT-223-3_TabPin2
Q4, Q5: MMBT3906; SOT-23
R1: 6.04k; R_0603_1608Metric
R2, R7, R15: 2.49k; R_0603_1608Metric
R3, R4, R6: 10k; R_0603_1608Metric
R5, R9, R10, R13, R14, R18: 100k; R_0603_1608Metric
R8: 2k; R_0603_1608Metric
R11, R12: 249k; R_0603_1608Metric
R16: 49.9; R_0603_1608Metric
R17: 432; R_0603_1608Metric
RV1, RV2: 50k; Potentiometer_Bourns_3269W_Vertical
TB1: 3.5mm; ScrewTerminal_1x02_P3.5mm_Horizontal_Black
TVS1: SMAJ33A; D_SMA
U1: LM4040DBZ-2.5; SOT-23
U2: TL431DBZ; SOT-23

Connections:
AGND: A1.2 (V-), A2.2 (V-), A3.2 (V-), C1.1, C2.2, C3.2, C5.1, C7.1, C8.1, C9.2, C10.1, C11.1, J1.2, R4.2, R7.2, R8.2, R12.2, R14.2, R16.2, R18.2, TVS1.2 (A2), U1.2 (A), U2.3 (A)
GAIN_FEED: Q3.3 (C), R1.2, R9.1, TB1.1
IN: C8.2, C9.1, D1.1 (K), Q1.3 (C), Q2.2 (C), Q2.4 (C), Q5.2 (E), R17.1, TVS1.1 (A1)
unnamed: A1.3 (+), R6.2, R7.1
unnamed: A1.4 (-), Q3.2 (E), R8.1
unnamed: A2.3 (+), R9.2, R12.1
unnamed: A2.4 (-), C4.2, R10.2, R11.2
unnamed: A3.4 (-), C6.2, Q2.3 (E), R16.1
unnamed: A3.1, C6.1, R15.1
unnamed: C5.2, R10.1, RV2.2
unnamed: D1.2 (A), J1.1
unnamed: Q1.1 (B), Q4.3 (C), R5.1, U2.1 (K)
unnamed: Q2.1 (B), R15.2
unnamed: A1.1, C3.1, Q3.1 (B)
unnamed: Q4.1 (B), Q5.3 (C), R18.1
unnamed: Q4.2 (E), Q5.1 (B), R17.2
unnamed: R11.1, RV1.1, RV1.2
unnamed: R13.2, RV2.1
unnamed: R14.1, RV2.3
unnamed: R3.2, R4.1, U2.2 (REF)
VCMD: A2.1, A3.3 (+), C4.1, RV1.3
VL: A1.5 (V+), A2.5 (V+), A3.5 (V+), C1.2, C2.1, C10.2, C11.2, Q1.2 (E), R2.1, R3.1, R5.2
VREF_U1: C7.2, R1.1, R2.2, R6.1, R13.1, TB1.2, U1.1 (K)

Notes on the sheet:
4-20mA
Thermistor
Pre-Regulator Section of Circuit
Output
Transient Suppression
Excitation
+5V Rail
Gain / Zero Amplifier

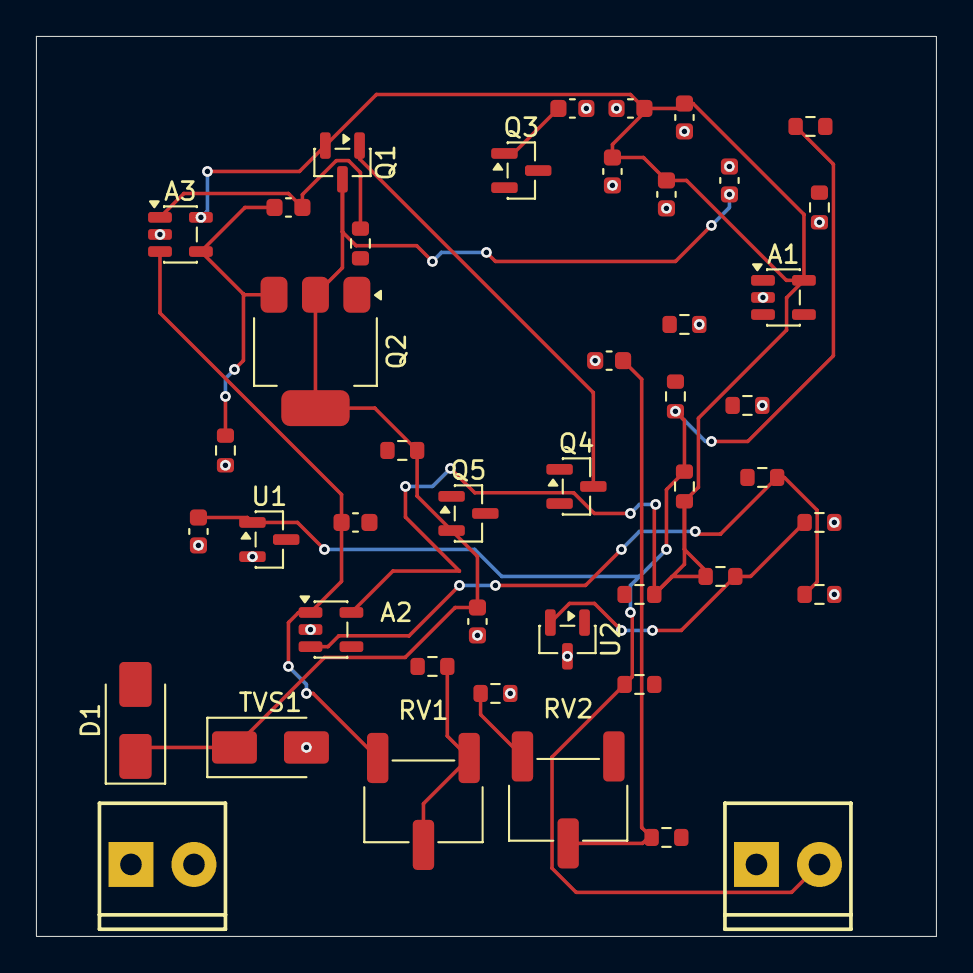
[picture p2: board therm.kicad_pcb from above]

Board: 4 copper layers, 50.0 x 50.0 mm, 45 parts (0 on the bottom side), 23 nets.

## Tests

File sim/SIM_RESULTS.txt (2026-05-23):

Note: No compatibility mode selected!

Circuit: * analog 4-20 ma ntc thermistor transmitter -- transfer-function verification

Doing analysis at TEMP = 27.000000 and TNOM = 27.000000

Using SPARSE 1.3 as Direct Linear Solver

No. of Data Rows : 61
 * analog 4-20 ma ntc thermistor transmitter -- transfer-function verification
 DC transfer characteristic  Sat May 23 15:09:25  2026
--------------------------------------------------------------------------------
Index   v-sweep         v(temp)         v(x)            v(vcmd)         
--------------------------------------------------------------------------------
0	-1.00000e+01	-1.00000e+01	1.163889e+00	1.900000e-01	
1	-9.00000e+00	-9.00000e+00	1.170960e+00	1.900000e-01	
2	-8.00000e+00	-8.00000e+00	1.178438e+00	1.900000e-01	
3	-7.00000e+00	-7.00000e+00	1.186191e+00	1.900000e-01	
4	-6.00000e+00	-6.00000e+00	1.194225e+00	1.900000e-01	
5	-5.00000e+00	-5.00000e+00	1.202540e+00	1.900000e-01	
6	-4.00000e+00	-4.00000e+00	1.211141e+00	1.900000e-01	
7	-3.00000e+00	-3.00000e+00	1.220028e+00	1.900000e-01	
8	-2.00000e+00	-2.00000e+00	1.229202e+00	1.900000e-01	
9	-1.00000e+00	-1.00000e+00	1.238664e+00	1.900000e-01	
10	0.000000e+00	0.000000e+00	1.248415e+00	1.900000e-01	
11	1.000000e+00	1.000000e+00	1.258453e+00	1.900000e-01	
12	2.000000e+00	2.000000e+00	1.268777e+00	1.900000e-01	
13	3.000000e+00	3.000000e+00	1.279386e+00	1.900000e-01	
14	4.000000e+00	4.000000e+00	1.290276e+00	1.900000e-01	
15	5.000000e+00	5.000000e+00	1.301445e+00	1.900000e-01	
16	6.000000e+00	6.000000e+00	1.312888e+00	1.900000e-01	
17	7.000000e+00	7.000000e+00	1.324601e+00	1.900000e-01	
18	8.000000e+00	8.000000e+00	1.336578e+00	1.900000e-01	
19	9.000000e+00	9.000000e+00	1.348813e+00	1.900000e-01	
20	1.000000e+01	1.000000e+01	1.361300e+00	1.900000e-01	
21	1.100000e+01	1.100000e+01	1.374031e+00	1.900000e-01	
22	1.200000e+01	1.200000e+01	1.386998e+00	1.900000e-01	
23	1.300000e+01	1.300000e+01	1.400192e+00	1.900000e-01	
24	1.400000e+01	1.400000e+01	1.413603e+00	1.900000e-01	
25	1.500000e+01	1.500000e+01	1.427223e+00	1.900000e-01	
26	1.600000e+01	1.600000e+01	1.441040e+00	1.900000e-01	
27	1.700000e+01	1.700000e+01	1.455043e+00	1.900000e-01	
28	1.800000e+01	1.800000e+01	1.469220e+00	1.900000e-01	
29	1.900000e+01	1.900000e+01	1.483560e+00	1.900000e-01	
30	2.000000e+01	2.000000e+01	1.498121e+00	2.000856e-01	
31	2.100000e+01	2.100000e+01	1.512676e+00	2.388507e-01	
32	2.200000e+01	2.200000e+01	1.527427e+00	2.781426e-01	
33	2.300000e+01	2.300000e+01	1.542289e+00	3.177260e-01	
34	2.400000e+01	2.400000e+01	1.557247e+00	3.575675e-01	
35	2.500000e+01	2.500000e+01	1.572289e+00	3.976302e-01	
36	2.600000e+01	2.600000e+01	1.587399e+00	4.378769e-01	
37	2.700000e+01	2.700000e+01	1.602565e+00	4.782703e-01	
38	2.800000e+01	2.800000e+01	1.617771e+00	5.187730e-01	
39	2.900000e+01	2.900000e+01	1.633005e+00	5.593478e-01	
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

Index   v-sweep         v(temp)         v(x)            v(vcmd)         
--------------------------------------------------------------------------------
55	4.500000e+01	4.500000e+01	1.869847e+00	1.025000e+00	
56	4.600000e+01	4.600000e+01	1.883646e+00	1.025000e+00	
57	4.700000e+01	4.700000e+01	1.897273e+00	1.025000e+00	
58	4.800000e+01	4.800000e+01	1.910721e+00	1.025000e+00	
59	4.900000e+01	4.900000e+01	1.923984e+00	1.025000e+00	
60	5.000000e+01	5.000000e+01	1.937058e+00	1.025000e+00	

 * analog 4-20 ma ntc thermistor transmitter -- transfer-function verification
 DC transfer characteristic  Sat May 23 15:09:25  2026
--------------------------------------------------------------------------------
Index   v-sweep         iloop_ma        headroom        
--------------------------------------------------------------------------------
0	-1.00000e+01	3.800000e+00	2.304999e+01	
1	-9.00000e+00	3.800000e+00	2.304999e+01	
2	-8.00000e+00	3.800000e+00	2.304999e+01	
3	-7.00000e+00	3.800000e+00	2.304999e+01	
4	-6.00000e+00	3.800000e+00	2.304999e+01	
5	-5.00000e+00	3.800000e+00	2.304999e+01	
6	-4.00000e+00	3.800000e+00	2.304999e+01	
7	-3.00000e+00	3.800000e+00	2.304999e+01	
8	-2.00000e+00	3.800000e+00	2.304999e+01	
9	-1.00000e+00	3.800000e+00	2.304999e+01	
10	0.000000e+00	3.800000e+00	2.304999e+01	
11	1.000000e+00	3.800000e+00	2.304999e+01	
12	2.000000e+00	3.800000e+00	2.304999e+01	
13	3.000000e+00	3.800000e+00	2.304999e+01	
14	4.000000e+00	3.800000e+00	2.304999e+01	
15	5.000000e+00	3.800000e+00	2.304999e+01	
16	6.000000e+00	3.800000e+00	2.304999e+01	
17	7.000000e+00	3.800000e+00	2.304999e+01	
18	8.000000e+00	3.800000e+00	2.304999e+01	
19	9.000000e+00	3.800000e+00	2.304999e+01	
20	1.000000e+01	3.800000e+00	2.304999e+01	
21	1.100000e+01	3.800000e+00	2.304999e+01	
22	1.200000e+01	3.800000e+00	2.304999e+01	
23	1.300000e+01	3.800000e+00	2.304999e+01	
24	1.400000e+01	3.800000e+00	2.304999e+01	
25	1.500000e+01	3.800000e+00	2.304999e+01	
26	1.600000e+01	3.800000e+00	2.304999e+01	
27	1.700000e+01	3.800000e+00	2.304999e+01	
28	1.800000e+01	3.800000e+00	2.304999e+01	
29	1.900000e+01	3.800000e+00	2.304999e+01	
30	2.000000e+01	4.001712e+00	2.299957e+01	
31	2.100000e+01	4.777015e+00	2.280574e+01	
32	2.200000e+01	5.562852e+00	2.260928e+01	
33	2.300000e+01	6.354520e+00	2.241136e+01	
34	2.400000e+01	7.151350e+00	2.221216e+01	
35	2.500000e+01	7.952603e+00	2.201184e+01	
36	2.600000e+01	8.757537e+00	2.181061e+01	
37	2.700000e+01	9.565405e+00	2.160864e+01	
38	2.800000e+01	1.037546e+01	2.140613e+01	
39	2.900000e+01	1.118696e+01	2.120326e+01	
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

Index   v-sweep         iloop_ma        headroom        
--------------------------------------------------------------------------------
55	4.500000e+01	2.050000e+01	1.887500e+01	
56	4.600000e+01	2.050000e+01	1.887500e+01	
57	4.700000e+01	2.050000e+01	1.887500e+01	
58	4.800000e+01	2.050000e+01	1.887500e+01	
59	4.900000e+01	2.050000e+01	1.887500e+01	
60	5.000000e+01	2.050000e+01	1.887500e+01	
ngspice-46 done

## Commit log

2026-05-23 Initial commit: analog 4-20 mA NTC thermistor transmitter
    Fully analog, 2-wire loop-powered 4-20 mA temperature transmitter built
    from multi-sourced parts, plus a tutorial in the instrumentation theory.
    Default build maps 20-40 C -> 4-20 mA for chocolate temperature control.
    - README.md: theory, single-resistor linearization, span-vs-conformity
    tradeoff, component-selection recipe for any range, schematic, BOM,
    calibration.
    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
2026-05-24 Add schematic + PCB; jellybean/SMD rework and device-level verification
    Round-2 review taking the transmitter from math-validated to schematic + rough PCB:
    - Pre-reg reference TLV431 -> stock TL431 (TL431DBZ, SOT-23); divider 10k/10k
    - CRD bias -> 2-transistor jellybean current source (Q4/Q5 + R17/R18)
    - All-SMD except field terminal blocks; SMD trimpots, SS14
    - Tolerance vs tempco: 1% everywhere, 25ppm only on R1/R8/R16; spec reframed to +/-0.1 C
    - Consolidated to 8 distinct resistor values
    - Net-by-net review fixed wiring bugs (A1 supply, LM4040, D1, IN rail, R2, R16 sense)
    - Device-level SPICE found gain-stage input loading bowing V(x) to +/-0.18 C;
    fixed via higher diff-amp input Z (1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
    [therm.kicad_pcb, therm.kicad_sch]
2026-05-24 README: add "Working with KiCad" gotchas section, refresh repo layout
    Document the KiCad workflow limitations hit building this board: connectivity
    can't be read from .kicad_sch coordinates (use kicad-cli netlist export); ERC
    misses wrong values/roles (49.9k vs 49.9 ohm, no-op caps, wrong supply pins);
    symbol variants differ in pin numbering (OPA333 D vs DBV); not all parts are in
    the stock library; footprints aren't auto-assigned; KiCad file hygiene.
